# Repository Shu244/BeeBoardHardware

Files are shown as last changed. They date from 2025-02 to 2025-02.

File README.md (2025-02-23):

# Overview

This repo contains a generic power supply for ESP32 and other MCUs. This board includes: 

1) Charging circuit with power path
2) Smart power button (for manually/programmtically controlling power)
3) Battery status  

The purpose of this board is to make an MCU portable with precise battery control and monitoring.

## Block Diagram

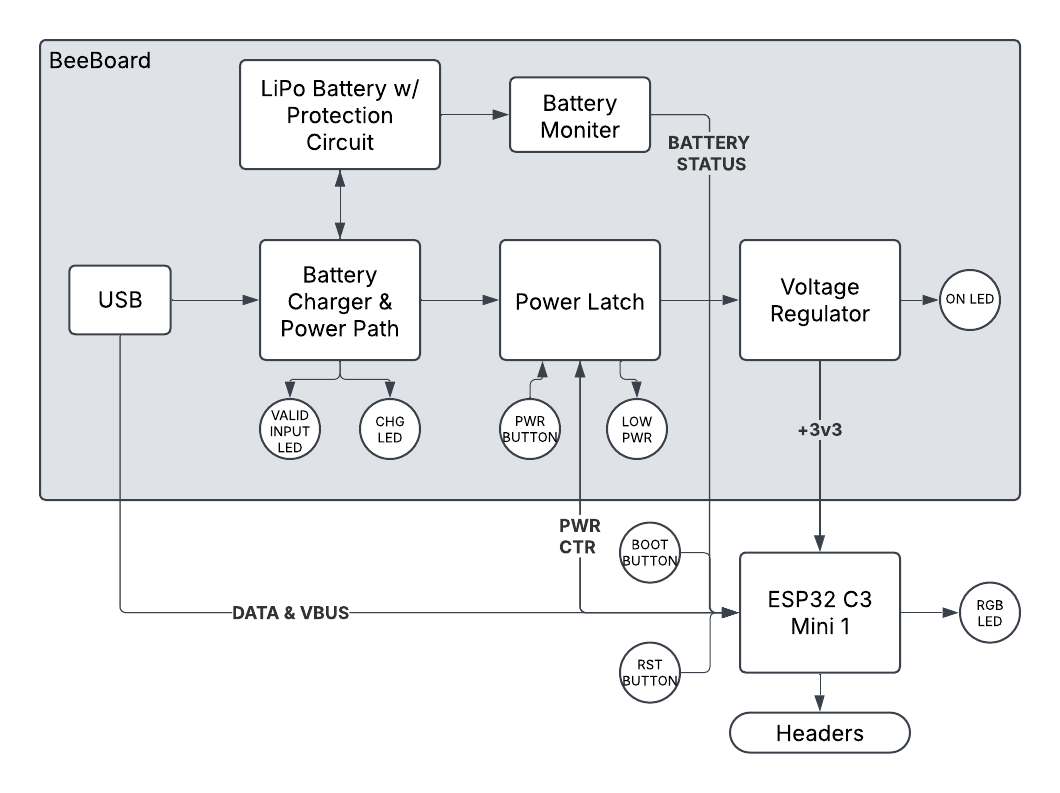
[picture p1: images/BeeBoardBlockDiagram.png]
BeeBoard block diagram


## Schematic

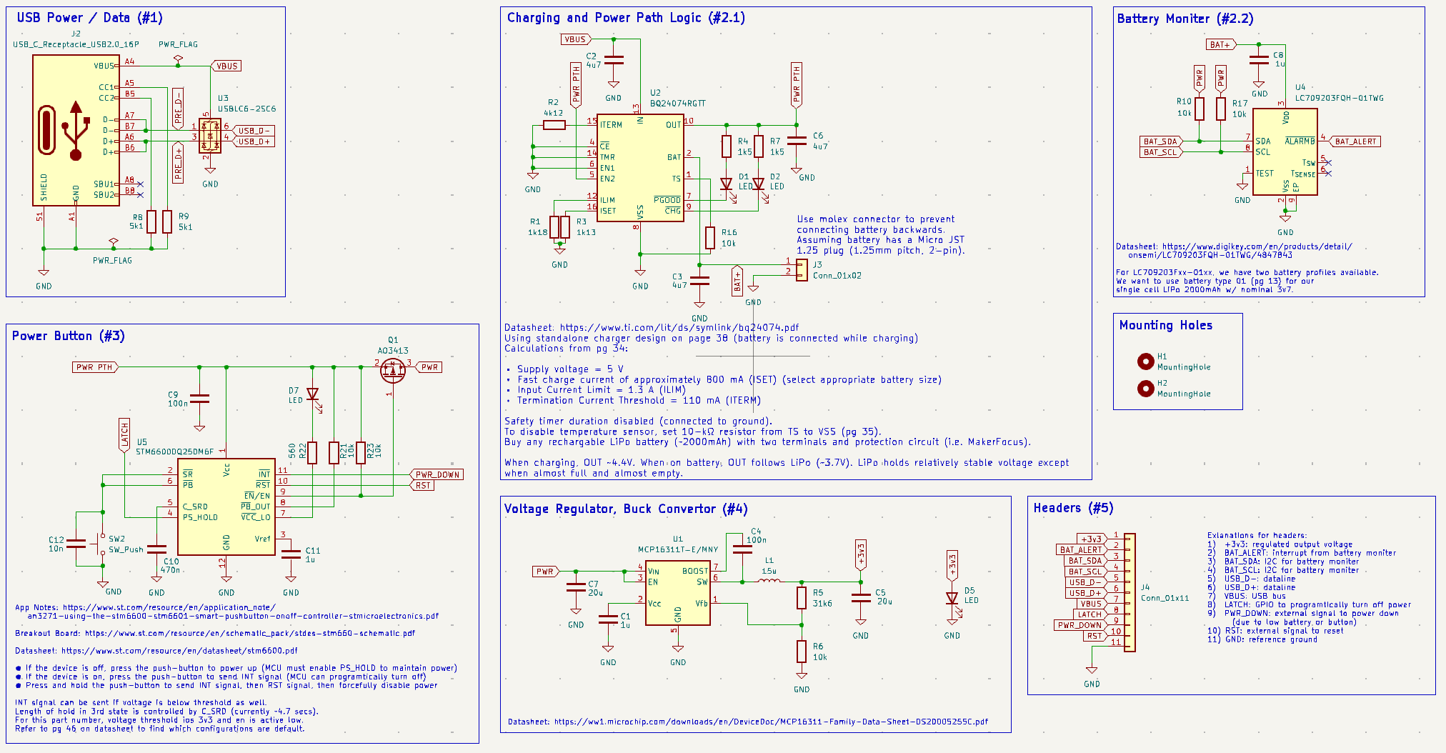
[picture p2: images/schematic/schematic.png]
BeeBoard schematic


## PCB

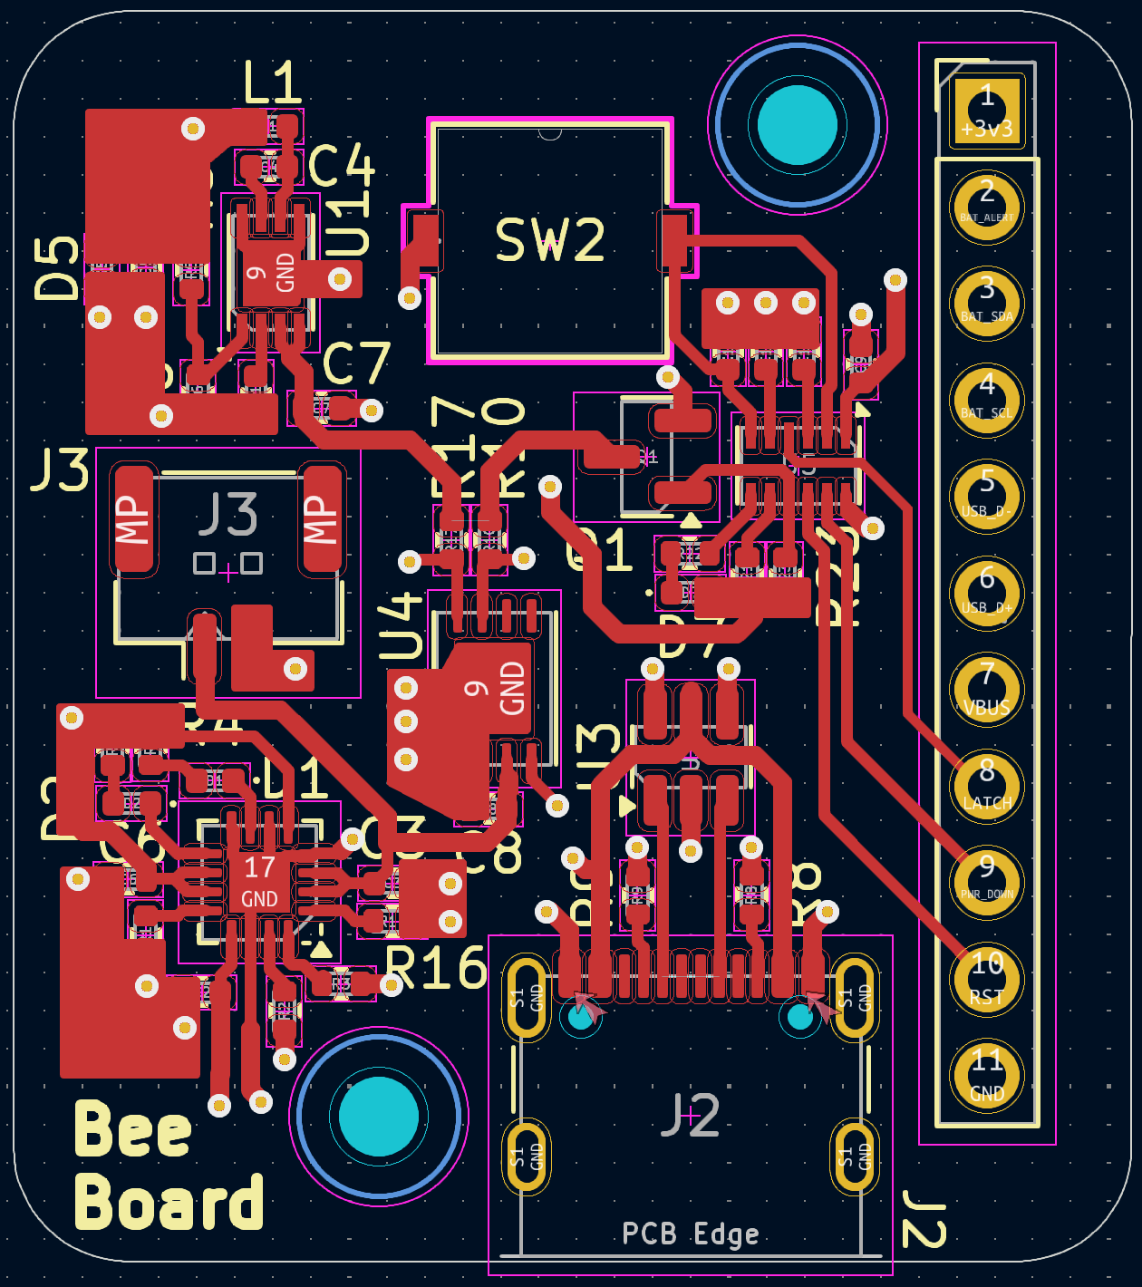
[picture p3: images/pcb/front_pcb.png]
BeeBoard PCB front


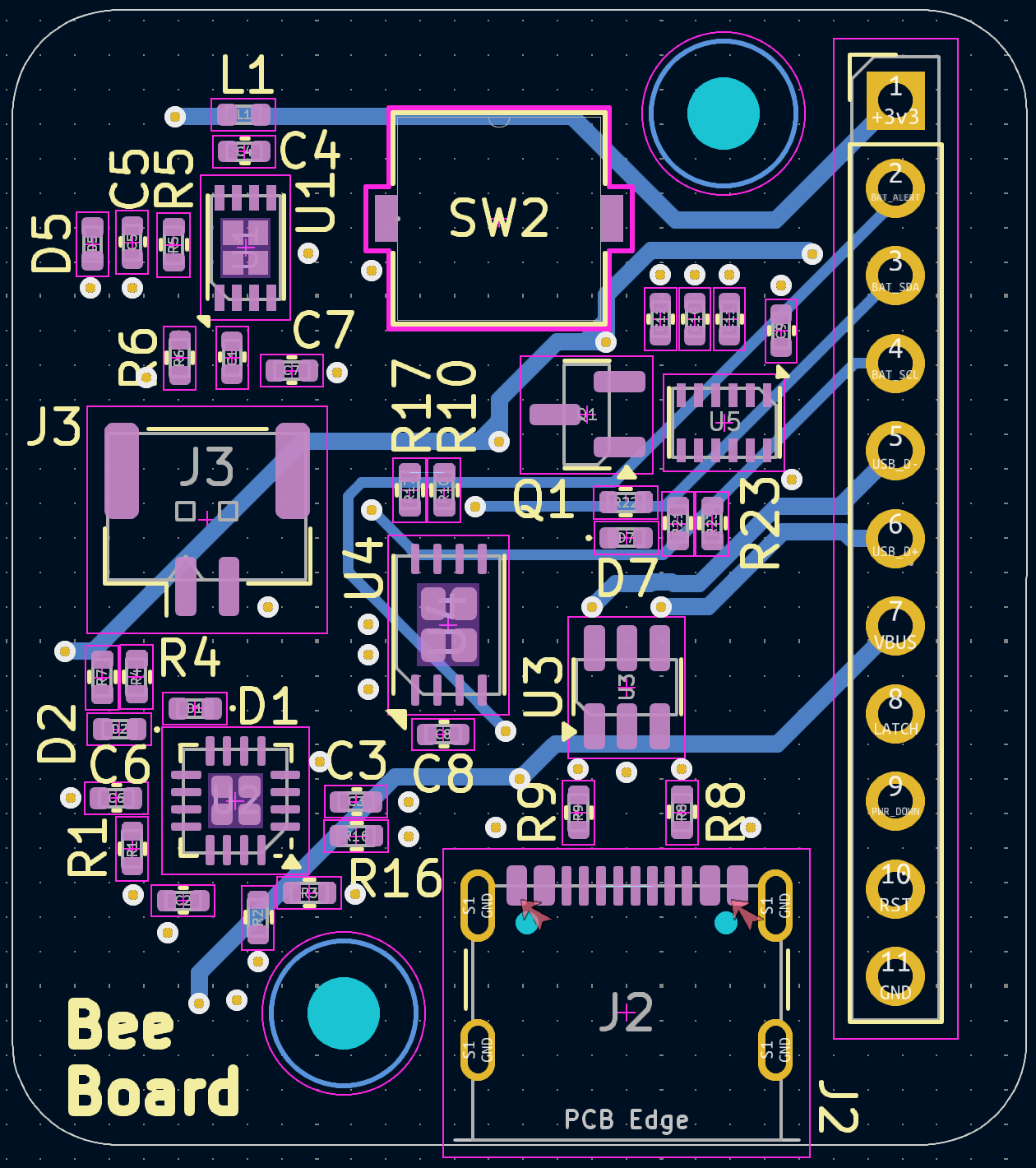
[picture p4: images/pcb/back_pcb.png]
BeeBoard PCB back


## 3D Models

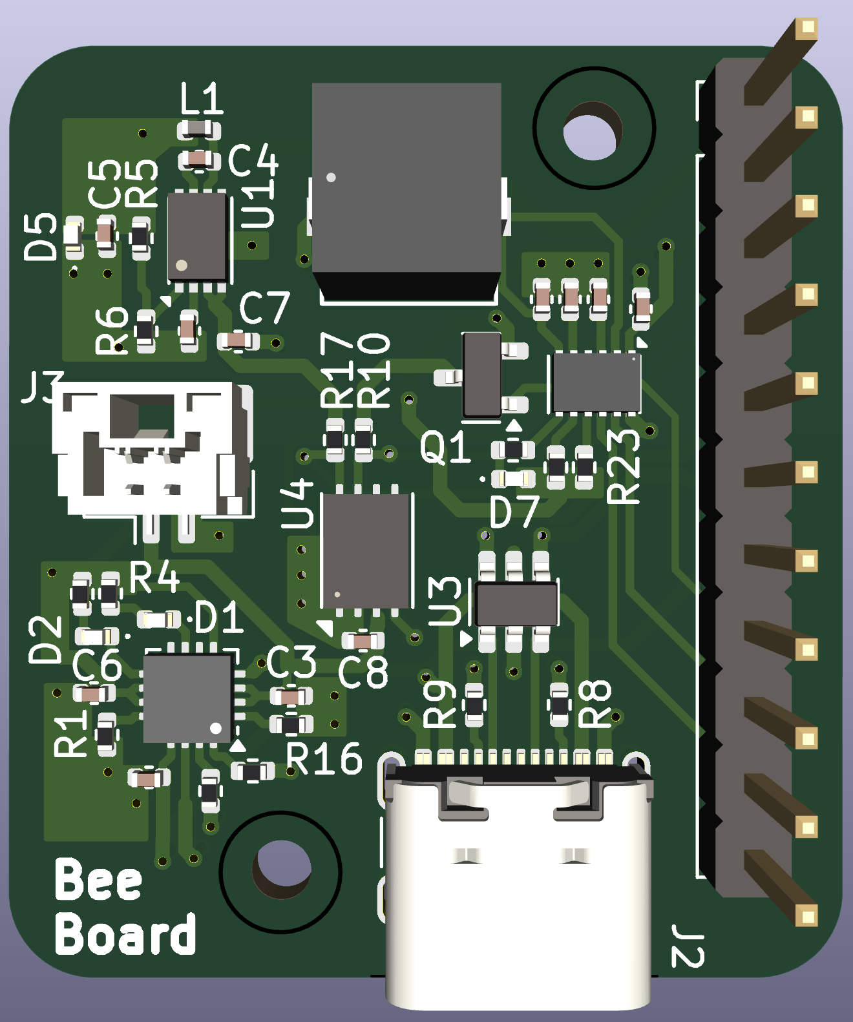
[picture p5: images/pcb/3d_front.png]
BeeBoard 3D Model front


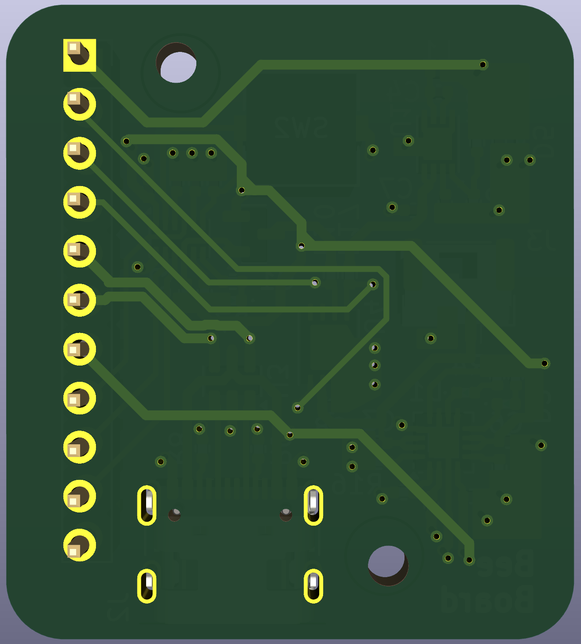
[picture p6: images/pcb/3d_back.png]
BeeBoard 3D Model back


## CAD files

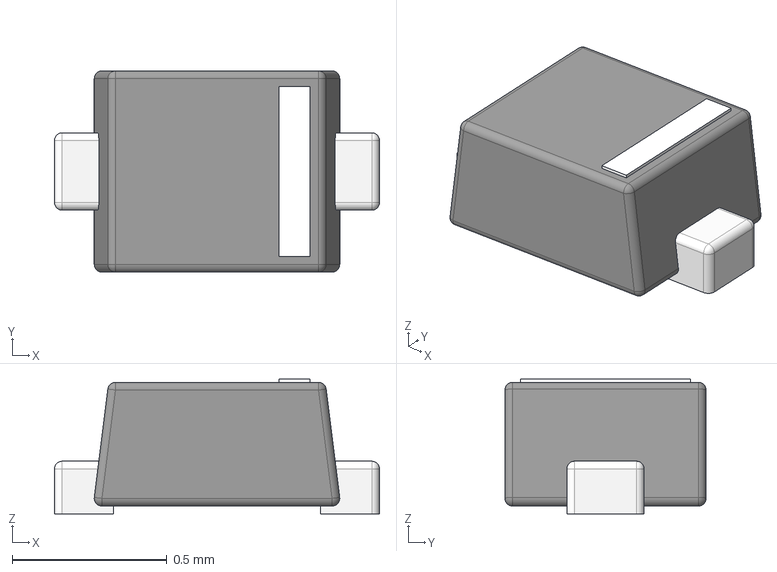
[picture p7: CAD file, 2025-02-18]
models/diode_0402.step
1.05 x 0.65 x 0.435 mm

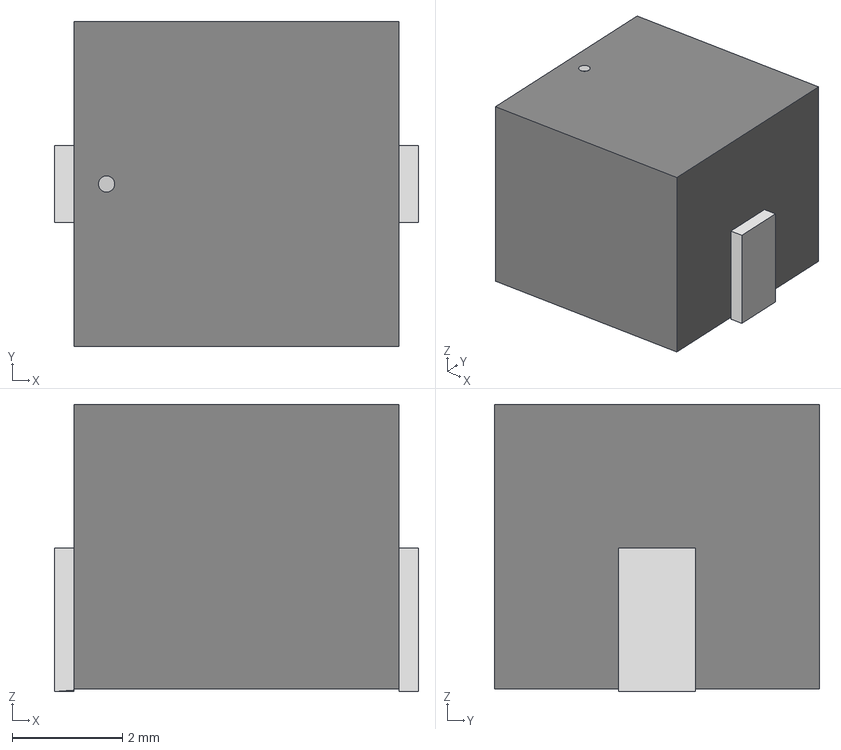
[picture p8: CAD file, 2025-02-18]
models/3983_switch.step
6.60 x 5.89 x 5.21 mm

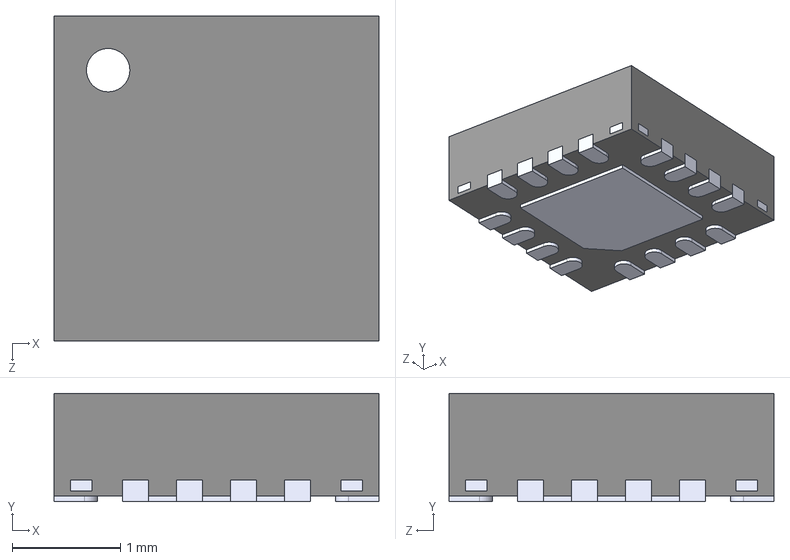
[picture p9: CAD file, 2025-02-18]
models/BQ24074RGTR.step
3.00 x 1.00 x 3.00 mm

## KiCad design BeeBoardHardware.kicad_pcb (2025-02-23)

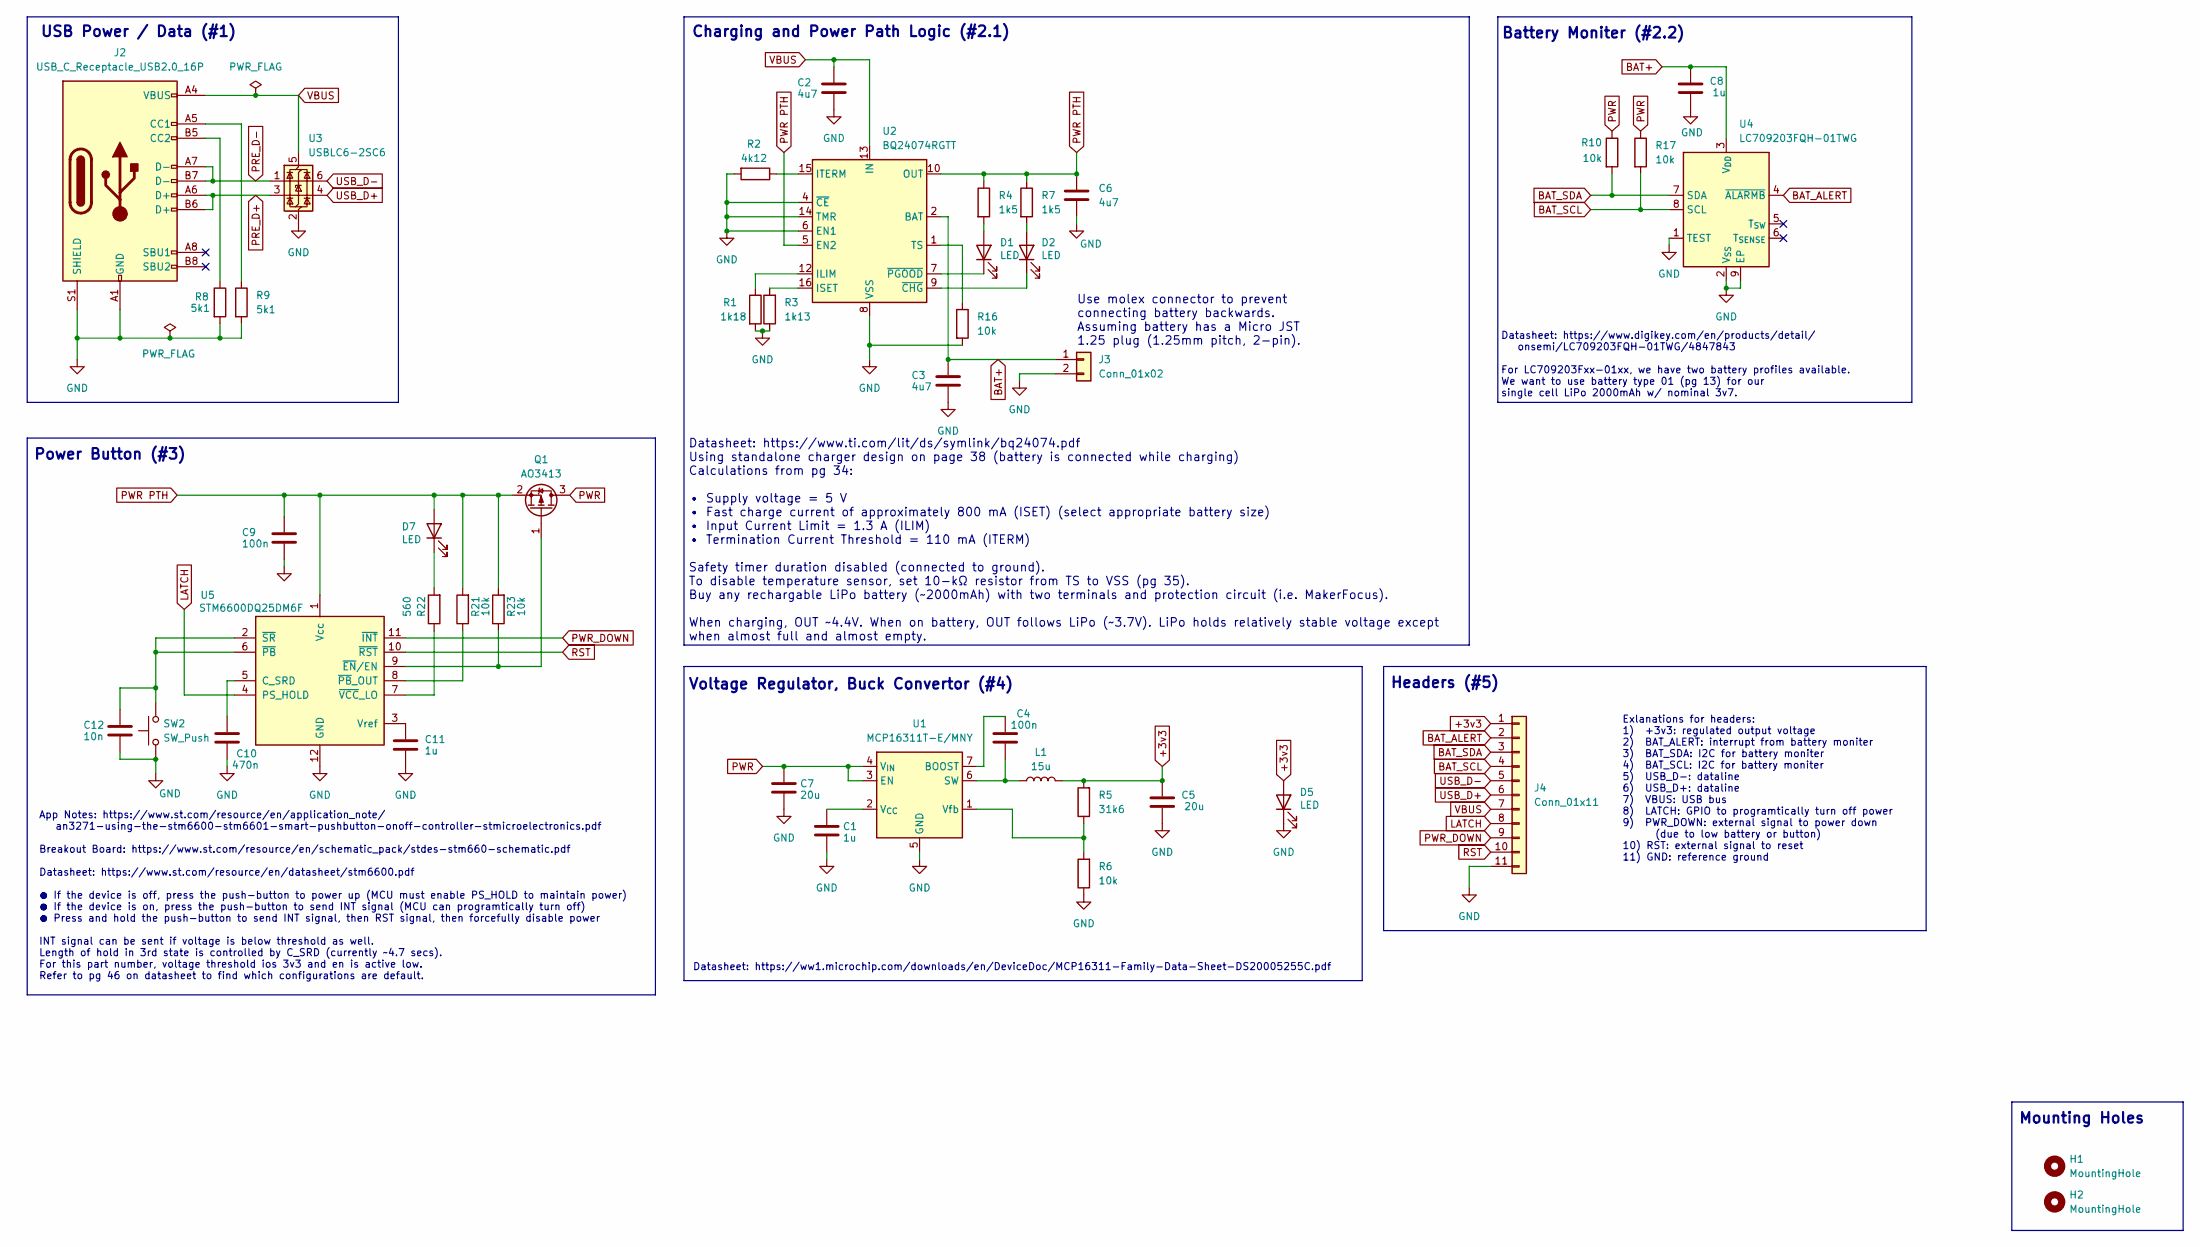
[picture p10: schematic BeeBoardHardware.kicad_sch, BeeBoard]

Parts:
C1, C8, C11: 1u; C_0402_1005Metric
C2, C3, C6: 4u7; C_0402_1005Metric
C4, C9: 100n; C_0402_1005Metric
C5, C7: 20u; C_0402_1005Metric
C10: 470n; C_0402_1005Metric
C12: 10n; C_0402_1005Metric
D1, D2, D5, D7: LED; LED_0402_1005Metric
H1, H2: MountingHole; MountingHole_2.1mm
J2: USB_C_Receptacle_USB2.0_16P; USB_C_Receptacle_GCT_USB4105-xx-A_16P_TopMnt_Horizontal
J3: Conn_01x02; JST_GH_BM02B-GHS-TBT_1x02-1MP_P1.25mm_Vertical
J4: Conn_01x11; PinHeader_1x11_P2.54mm_Vertical
L1: 15u; L_0402_1005Metric
Q1: AO3413; SOT-23
R1: 1k18; R_0402_1005Metric
R2: 4k12; R_0402_1005Metric
R3: 1k13; R_0402_1005Metric
R4, R7: 1k5; R_0402_1005Metric
R5: 31k6; R_0402_1005Metric
R6, R10, R16, R17, R21, R23: 10k; R_0402_1005Metric
R8, R9: 5k1; R_0402_1005Metric
R22: 560; R_0402_1005Metric
SW2: SW_Push; 3983_switch
U1: MCP16311T-E/MNY; DFN-8-1EP_3x2mm_P0.5mm_EP1.75x1.45mm
U2: BQ24074RGTT; VQFN-16-1EP_3x3mm_P0.5mm_EP1.6x1.6mm
U3: USBLC6-2SC6; SOT-23-6
U4: LC709203FQH-01TWG; WDFN-8-1EP_4x3mm_P0.65mm_EP2.4x1.8mm
U5: STM6600DQ25DM6F; TDFN-12_2x3mm_P0.5mm

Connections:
+3v3: C5.1, D5.2 (A), J4.1, L1.2, R5.2
BAT+: C3.1, C8.1, J3.1, U2.2 (BAT), U2.3 (BAT), U4.3 (V_{DD})
BAT_ALERT: J4.2, U4.4 (~ALARMB)
BAT_SCL: J4.4, R17.2, U4.8 (SCL)
BAT_SDA: J4.3, R10.2, U4.7 (SDA)
GND: C1.2, C2.2, C3.2, C5.2, C6.2, C7.2, C8.2, C9.2, C10.2, C11.2, C12.2, D5.1 (K), J2.A1 (GND), J2.A12 (GND), J2.B1 (GND), J2.B12 (GND), J2.S1 (SHIELD), J3.2, J4.11, R1.2, R2.2, R3.1, R6.1, R8.2, R9.2, R16.2, SW2.1, U1.5 (GND), U1.8 (GND), U1.9 (GND), U2.4 (~CE), U2.6 (EN1), U2.8 (VSS), U2.14 (TMR), U2.17 (VSS), U3.2 (GND), U4.1 (TEST), U4.2 (V_{SS}), U4.9 (EP), U5.12 (GND)
LATCH: J4.8, U5.4 (PS_HOLD)
unnamed: D1.2 (A), R4.2
unnamed: D1.1 (K), U2.7 (~PGOOD)
unnamed: D2.2 (A), R7.2
unnamed: D2.1 (K), U2.9 (~CHG)
unnamed: D7.1 (K), R22.2
unnamed: J2.A5 (CC1), R9.1
unnamed: J2.B5 (CC2), R8.1
unnamed: Q1.1 (G), R23.1, U5.9 (~EN/EN)
unnamed: C4.2, U1.7 (BOOST)
unnamed: C4.1, L1.1, U1.6 (SW)
unnamed: C1.1, U1.2 (V_{CC})
unnamed: R5.1, R6.2, U1.1 (Vfb)
unnamed: R1.1, U2.12 (ILIM)
unnamed: R3.2, U2.16 (ISET)
unnamed: R2.1, U2.15 (ITERM)
unnamed: R16.1, U2.1 (TS)
unnamed: C10.1, U5.5 (C_SRD)
unnamed: C11.1, U5.3 (Vref)
unnamed: C12.1, SW2.2, U5.2 (~SR), U5.6 (~PB)
unnamed: R21.1, U5.8 (~PB_OUT)
unnamed: R22.1, U5.7 (~VCC_LO)
PRE_D+: J2.A6 (D+), J2.B6 (D+), U3.3 (I/O2)
PRE_D-: J2.A7 (D-), J2.B7 (D-), U3.1 (I/O1)
PWR: C7.1, Q1.3 (D), R10.1, R17.1, U1.3 (EN), U1.4 (V_{IN})
PWR PTH: C6.1, C9.1, D7.2 (A), Q1.2 (S), R4.1, R7.1, R21.2, R23.2, U2.5 (EN2), U2.10 (OUT), U2.11 (OUT), U5.1 (Vcc)
PWR_DOWN: J4.9, U5.11 (~INT)
RST: J4.10, U5.10 (~RST)
USB_D+: J4.6, U3.4 (I/O2)
USB_D-: J4.5, U3.6 (I/O1)
VBUS: C2.1, J2.A4 (VBUS), J2.A9 (VBUS), J2.B4 (VBUS), J2.B9 (VBUS), J4.7, U2.13 (IN), U3.5 (VBUS)

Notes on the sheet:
Use molex connector to prevent connecting battery backwards. Assuming battery has a Micro JST 1.25 plug (1.25mm pitch, 2-pin).
Power Button (#3)
Headers (#5)
Datasheet: https://www.ti.com/lit/ds/symlink/bq24074.pdf Using standalone charger design on page 38 (battery is connected while charging) Calculations from pg 34: • Supply voltage = 5 V • Fast charge current of approximately 800 mA (ISET) (select appropriate battery size) • Input Current Limit = 1.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
Exlanations for headers: 1) +3v3: regulated output voltage 2) BAT_ALERT: interrupt from battery moniter 3) BAT_SDA: I2C for battery moniter 4) BAT_SCL: I2C for battery moniter 5) USB_D-: dataline 6) USB_D+: dataline 7) VBUS: USB bus 8) LATCH: GPIO to programtically turn off power 9) PWR_DOWN: exter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
Mounting Holes
Datasheet: https://ww1.microchip.com/downloads/en/DeviceDoc/MCP16311-Family-Data-Sheet-DS20005255C.pdf
Datasheet: https://www.digikey.com/en/products/detail/ onsemi/LC709203FQH-01TWG/4847843 For LC709203Fxx−01xx, we have two battery profiles available. We want to use battery type 01 (pg 13) for our single cell LiPo 2000mAh w/ nominal 3v7.
USB Power / Data (#1)
Voltage Regulator, Buck Convertor (#4)
App Notes: https://www.st.com/resource/en/application_note/ an3271-using-the-stm6600-stm6601-smart-pushbutton-onoff-controller-stmicroelectronics.pdf Breakout Board: https://www.st.com/resource/en/schematic_pack/stdes-stm660-schematic.pdf Datasheet: https://www.st.com/resource/en/datasheet/stm6600.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
Battery Moniter (#2.2)
Charging and Power Path Logic (#2.1)

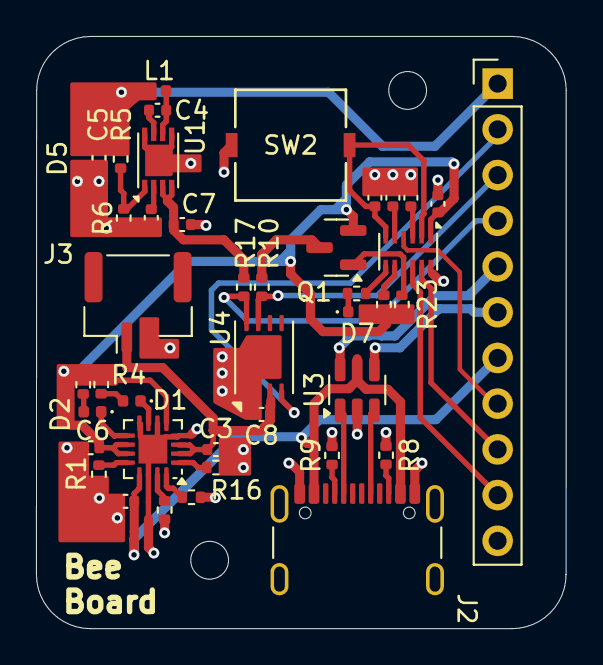
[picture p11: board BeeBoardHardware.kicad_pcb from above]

Board: 4 copper layers, 29.4 x 32.9 mm, 44 parts (0 on the bottom side), 37 nets.

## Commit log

2025-02-15 add readme and updated schematic
    [BeeBoardHardware.kicad_sch]
2025-02-16 added battery monitor
    [BeeBoardHardware.kicad_sch]
2025-02-17 updated schematic
    [BeeBoardHardware.kicad_sch]
2025-02-18 assign footprints
    [3983_switch.step, BeeBoardHardware.kicad_sch]
2025-02-18 updated stepper files
    [BQ24074RGTR.step, BeeBoardHardware.kicad_pcb, BeeBoardHardware.kicad_sch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]
2025-02-19 organized pcb
    [BeeBoardHardware.kicad_pcb, BeeBoardHardware.kicad_sch]
2025-02-21 updated schematics and PCB
    [BeeBoardHardware.kicad_pcb, BeeBoardHardware.kicad_sch]
2025-02-22 setup all gnd vias and organized parts
    [BeeBoardHardware.kicad_pcb]
2025-02-22 routed more traces
    [BeeBoardHardware.kicad_pcb, BeeBoardHardware.kicad_sch]
2025-02-22 routing headers next
    [BeeBoardHardware.kicad_pcb, BeeBoardHardware.kicad_sch]
2025-02-23 finish routes
    [BeeBoardHardware.kicad_pcb]
2025-02-23 clean up silkscreen
    [BeeBoardHardware.kicad_pcb]
2025-02-23 added images
    [BeeBoardHardware.kicad_sch]
